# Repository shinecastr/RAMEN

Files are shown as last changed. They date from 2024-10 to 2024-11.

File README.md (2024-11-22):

# RAMEN

## Ryan's Awesome Multi-Effects Node

RAMEN is an open music technology project created for my Music and Sound Recording Capstone for the University of New Haven. 

RAMEN relies on [Patchbox OS 2024-04-04](https://community.blokas.io/t/beta-patchbox-os-bookworm-arm64-2024-04-04/5163) and PureData Vanilla 0.53

## Build Your Own

### Componenents

- Raspberry Pi 5 8 GB
- HiFiBerry DAC2 ADC Pro
- Pimoroni NVMe Base
- NVMe SSD
- Hoysond 5 in. Touch Screen Display 

### Misc. Components

- (2) 1/4" Female TS Connectors
- Male RCA Connector
- 1/8" Male TRS Connector
- M3 hardware

### Assembly

1. Print out the provided case files
2. Attach the HiFiBerry hat to the Pi
3. Install the SSD and attach the NVMe base to the Pi with the provided flex cable
4. Screw the Pi into the case from below
5. Attach the screen to the Pi via  HDMI and USB
6. Screw in the lid, securing the display

## Setup and Configuration

### Preparing the OS Image

- Download the latest Patchbox OS image from the link above
- Mount the image to your device by double-clicking
- Replace config.txt with the [included file](./config.txt) or make the following changes

#### Uncomment

```bash 
dtparam=i2c_arm=on
dtparam=i2s=on
dtparam=spi=on
```

#### Comment Out

``` bash
#dtparam=audio=on
```

#### Add

```bash
dtoverlay=hifiberry-dacplusadcpro

[all]
force_eeprom_read=0
dtoverlay=w1-gpio
```

#### Edit

```bash
dtoverlay=vc4-kms-v3d -> dtoverlay=vc4-kms-v3d,noaudio
```

Unmount the edited image and flash it to an NVMe SSD using [Balena Etcher](https://balenaetcher.io) or another disk imaging tool

### Patchbox Config

**The default user is `patch` and its password is `blokaslabs`**

You can skip through the Jack settings in the Initial Setup Wizard as RAMEN relies on the ALSA audio backend

Enter the Patchbox Configuration Utility by typing `patchbox` in the terminal and make the following selections 

```
boot > environment > desktop autologin
module > none
jack > stop
kernel > install-rt
```

Run `./hide_cursor.sh` to hide the cursor 

### ALSA Config

#### Enter the ALSA config tool by entering `alsamixer` in the terminal

- Press F6 and select `snd_rpi_hifiberry_dacplusadcpro`
- Set `ADC Left Input` to `[{VIN1p, VIN1M}[DIFF]]`
- Set `ADC Mic Bias` to `[Mic Bias Off]`

### PureData Config

#### PureData can be launched with the desktop shortcut or by typing `puredata` into a terminal window

**Under the Media tab select DSP On and ALSA then enter Audio Settings**

- Sample rate: 192000
- Delay (msec): 5
- Block size 64
- Input Devices: snd_rpi_hifiberry_dacplusadcpro (hardware)
- Output Devices: snd_rpi_hifiberry_dacplusadcpro (hardware)

Install the kiosk-plugin external through PureData's built-in external manager

Edit kiosk.cfg and set the following parameters

```
KioskNewWindow True
ShowMenu False
FullScreen True
QuitOnClose False
HidePopup True
ScrollBars False
```

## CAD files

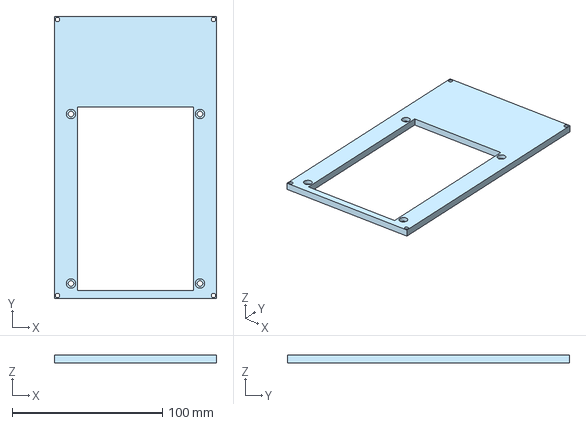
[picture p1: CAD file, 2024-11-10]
3d_files/RAMEN_Lid.step
108.0 x 188.0 x 5.00 mm

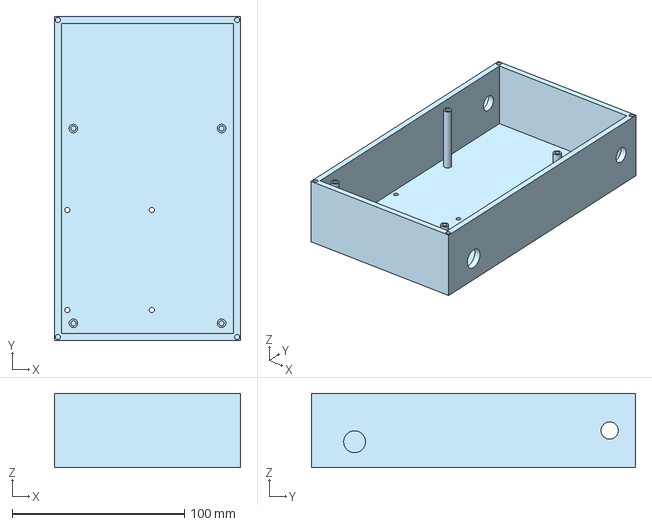
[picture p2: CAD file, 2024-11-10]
3d_files/RAMEN_Case.step
108.0 x 188.0 x 43.1 mm

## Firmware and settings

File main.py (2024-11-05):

#!/usr/bin/python3
from gpiozero import Button
import pyautogui as gui

class KeyHandler:
    def __init__(self, _pin, _output):
        self.output = _output
        self.button = Button(_pin)

    def Handle(self):
        if self.button.is_pressed:
            gui.keyDown(self.output)
        if self.button.is_released:
            gui.keyDown(self.output)


k1 = KeyHandler(4, 'q')
k2 = KeyHandler(17, 'w')
k3 = KeyHandler(18, 'a')
k4 = KeyHandler(27, 's')
k5 = KeyHandler(22, 'z')
k6 = KeyHandler(23, 'x')
k7 = KeyHandler(24, 'k')

keys = [k1, k2, k3, k4, k5, k6, k7]

while 1:
    for item in keys:
        item.Handle()

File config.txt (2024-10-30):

# For more options and information see
# http://rptl.io/configtxt
# Some settings may impact device functionality. See link above for details

# Uncomment some or all of these to enable the optional hardware interfaces
dtparam=i2c_arm=on
dtparam=i2s=on
dtparam=spi=on

# Enable audio (loads snd_bcm2835)
#dtparam=audio=on
dtoverlay=hifiberry-dacplusadcpro

# Additional overlays and parameters are documented
# /boot/firmware/overlays/README

# Automatically load overlays for detected cameras
camera_auto_detect=1

# Automatically load overlays for detected DSI displays
display_auto_detect=1

# Automatically load initramfs files, if found
auto_initramfs=1

# Enable DRM VC4 V3D driver
dtoverlay=vc4-kms-v3d,noaudio
max_framebuffers=2

# Don't have the firmware create an initial video= setting in cmdline.txt.
# Use the kernel's default instead.
disable_fw_kms_setup=1

# Run in 64-bit mode
arm_64bit=1

# Disable compensation for displays with overscan
disable_overscan=1

# Run as fast as firmware / board allows
arm_boost=1

[cm4]
# Enable host mode on the 2711 built-in XHCI USB controller.
# This line should be removed if the legacy DWC2 controller is required
# (e.g. for USB device mode) or if USB support is not required.
otg_mode=1

[all]
force_eeprom_read=0
dtoverlay=w1-gpio

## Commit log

2024-10-30 readme changes
    [config.txt]
2024-11-10 added case model
    [RAMEN_Case.step, RAMEN_Lid.step]
